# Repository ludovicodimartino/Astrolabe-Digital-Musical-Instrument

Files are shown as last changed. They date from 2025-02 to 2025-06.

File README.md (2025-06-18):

# Astrolabio project

Research training project for the Master's Degree Program in Computer Engineering. The topic of the activity is the design and development of the digital musical instrument based on the astrolabe from the [_Giovanni Poleni_ museum](https://www.musei.unipd.it/it/fisica#) in Padua for the show _Caravanserraglio_.

## Project Structure

```
Astrolabio project
│
└───Arduino Sketches                   # The developed sketches for the Arduino board
│
└───Controller Design                  # The designed parts for building the physical controller
│
└───Digital Twin Desktop Application   # Electron app for viewing the 3D astrolabe model
│
└───Fritzing Breadboard Diagrams       # The design of the breadboards for the first and second design iteration
│
└───PureData Patches                   # The developed Pure Data patches
│   │
│   └───abstractions                   # Reusable Pure Data Objects for reading the sensor data from the network
│   │
│   └───tests                          # Patches for testing the communication with the Arduino
│
└─── README.md
```

## Hardware Components

For the final prototype, the following components were used:

-   [ESP32-C3 Super Mini Dev Board](https://www.espboards.dev/esp32/esp32-c3-super-mini/)
-   [Adafruit Precision NXP 9-DOF Breakout Board - FXOS8700 + FXAS21002](https://www.adafruit.com/product/3463)
-   [Dual rotary encoder](https://docs.rs-online.com/f0a8/A700000009887456.pdf)
-   [LiPo Rider Plus](https://wiki.seeedstudio.com/Lipo-Rider-Plus/)
-   LiPo Battery 3.7V 1800mAh

For the communication between the microcontroller and the IMU (Adafruit Precision NXP 9-DOF), the I<sup>2</sup>C serial communication system was used. Here’s how everything was wired:
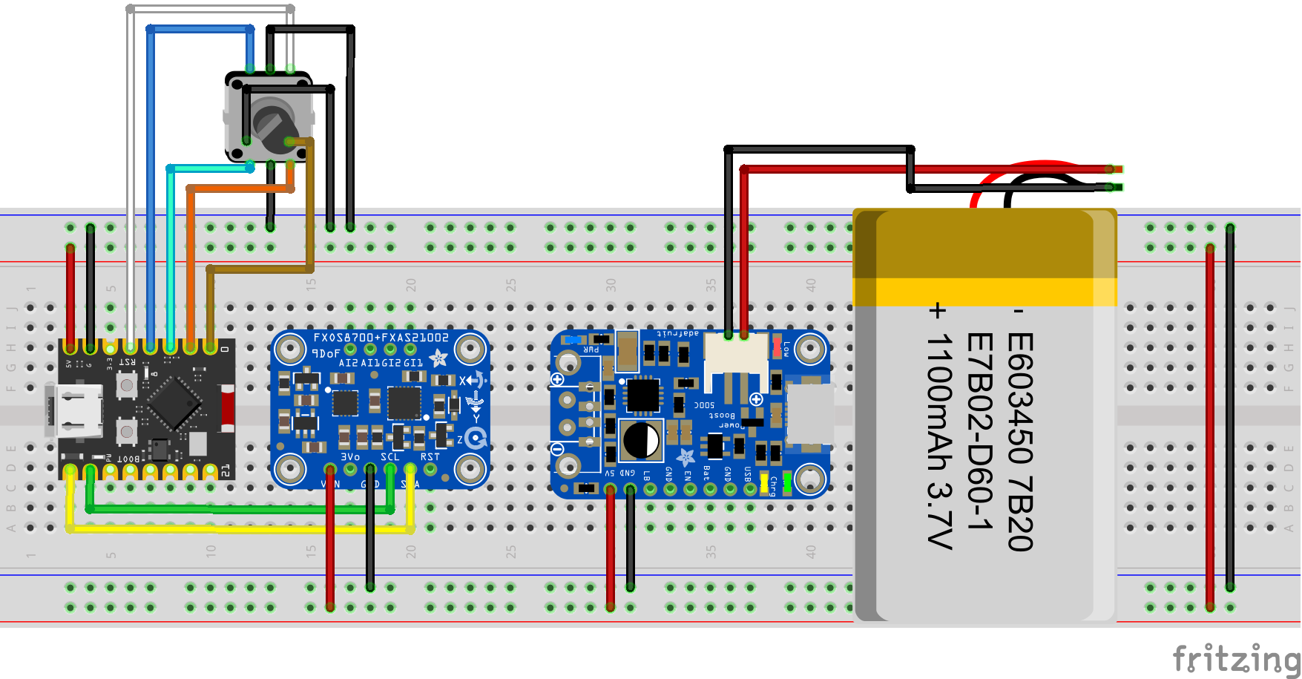
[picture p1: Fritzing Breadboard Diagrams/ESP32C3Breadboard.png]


## How to run the Arduino DMI code on the ESP32-C3 Dev board

1.  In the Arduino IDE, go to File->Preferences and under _Additional boards manager URLs_ paste this URL:

        https://raw.githubusercontent.com/espressif/arduino-esp32/gh-pages/package_esp32_index.json

    If you have other URLs you can separate them using a comma.

2.  In the Arduino IDE, go to the library manager and install all the necessary libraries:
    - [WiFi101](https://docs.arduino.cc/libraries/wifi101/)
    - [Adafruit AHRS](https://github.com/adafruit/Adafruit_AHRS)
    - [Adafruit FXAS21002C](https://github.com/adafruit/Adafruit_FXAS21002C)
    - [Adafruit FXOS8700](https://github.com/adafruit/Adafruit_FXOS8700)
    - [OSC](https://github.com/CNMAT/OSC)
3.  Write the necessary information in the [secrets.h](./Arduino%20Sketches/ESP32C3_send_IMU_and_encoder_Data_OSC/secrets.h) file to allow the board to access WiFi. If the file doesn't exist create it in the sketch directory.
4. In the Arduino IDE, enable the USB CDC on boot (*Tools -> USB CDC On Boot -> Enabled*).
5. Connect the board to the computer, compile and upload the code.

## How to run the Electron App 

### Production version (Windows)
From the [releases](https://github.com/ludovicodimartino/astrolabio-arduino/releases) download the latest Installer version.
Run the installer on your laptop and the program should start automatically.

### Dev version
You must have node.js installed in your system. You can download it from [here](https://nodejs.org/en).

Clone the repository.

Navigate to the [Digital Twin Desktop Application](./Digital%20Twin%20Desktop%20Application/) folder and run the following command:

    npm install

To start the application in development mode run:

    npm start

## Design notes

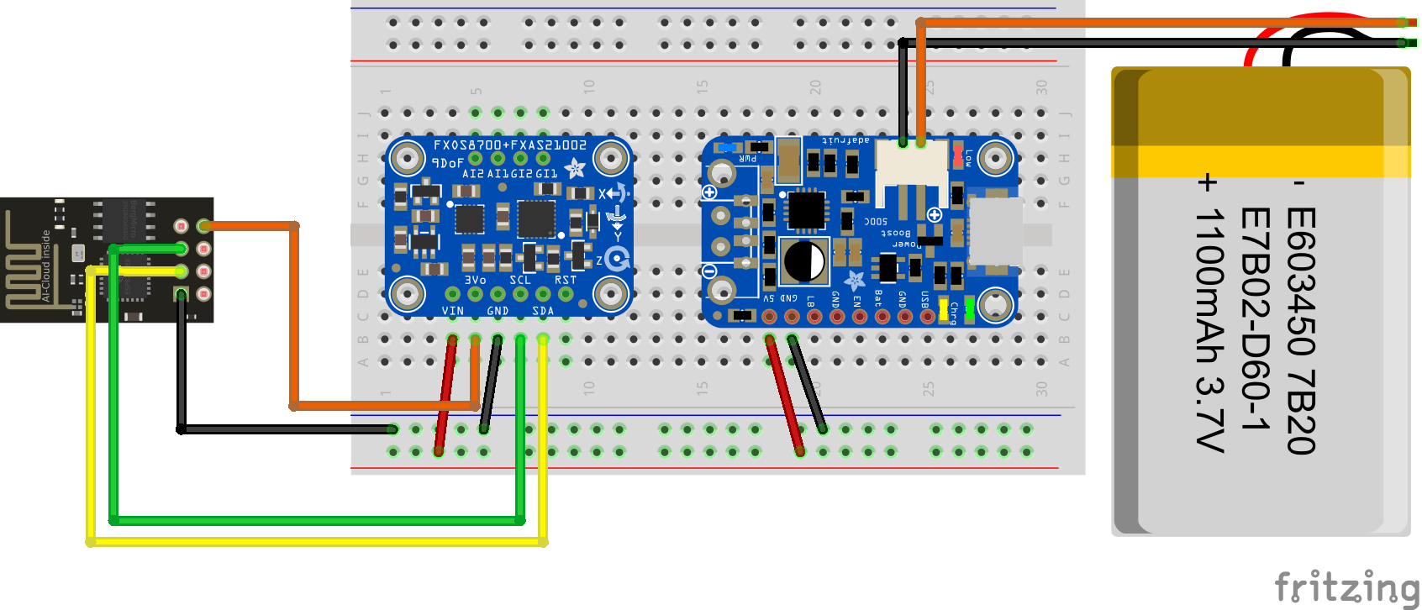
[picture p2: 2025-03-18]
Fritzing Breadboard Diagrams/ESP01SBreadboard.png

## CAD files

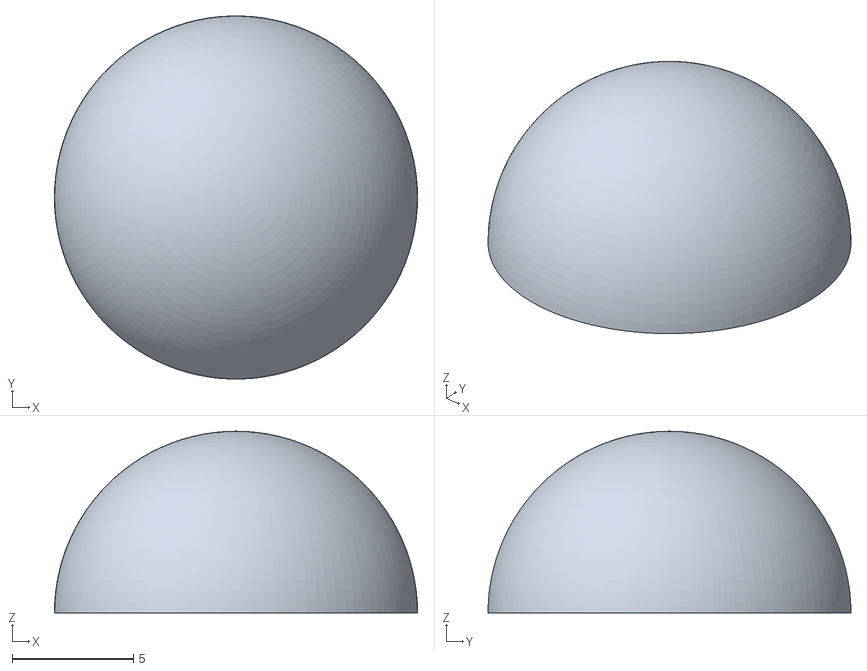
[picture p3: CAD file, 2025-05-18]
Controller Design/Second Iteration/3D Models Rotary Encoder Interface/alidada_interface_with_rotary_encoder.stl
15.0 x 15.0 x 7.50

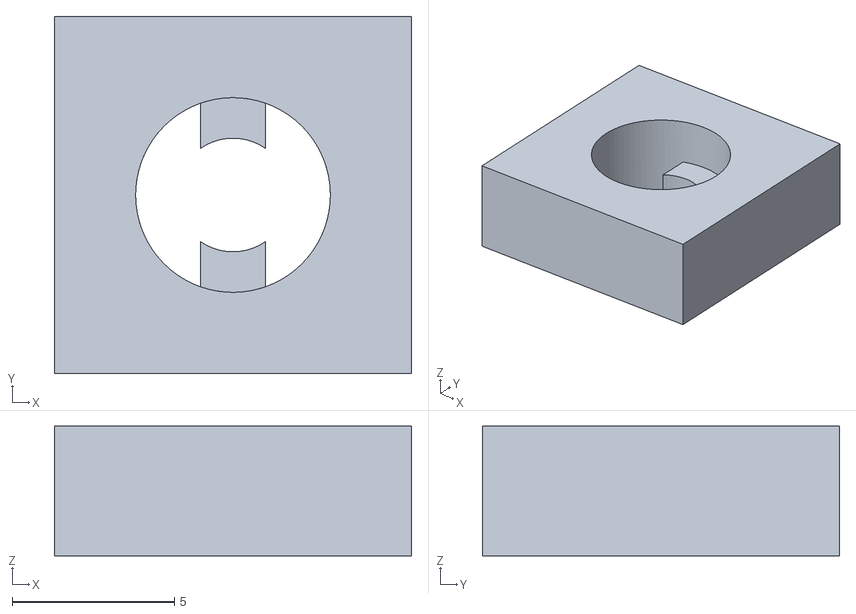
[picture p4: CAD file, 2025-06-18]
Controller Design/Third Iteration/3D Models Rotary Encoder Interface/rete_interface_with_rotary_encoder.stl
11.0 x 11.0 x 4.00

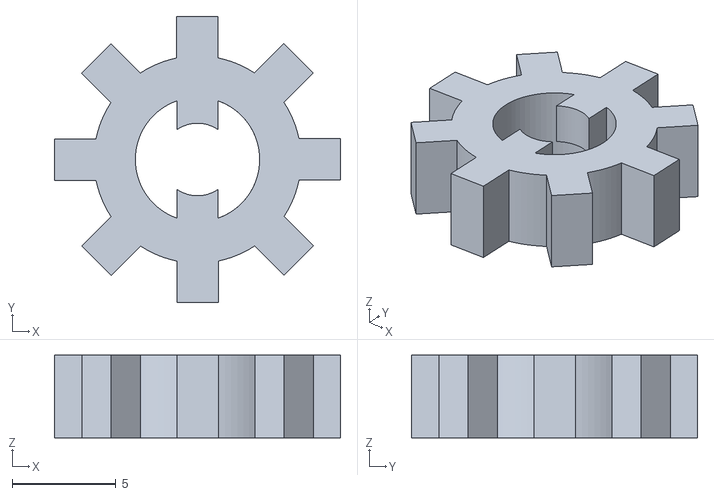
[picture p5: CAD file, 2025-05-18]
Controller Design/Second Iteration/3D Models Rotary Encoder Interface/rete_interface_with_rotary_encoder.stl
13.8 x 13.8 x 4.00

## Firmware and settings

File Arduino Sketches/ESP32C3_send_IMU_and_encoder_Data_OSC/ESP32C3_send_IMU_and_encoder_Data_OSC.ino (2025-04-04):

/**
 * CODE FOR ESP32C3 superMini
 * N.B. REMEMBER TO CREATE THE secrets.h FILE THE WIFI CREDENTIALS AS FOLLOWS
 * #define SECRET_SSID "NetworkName"
 * #define SECRET_PASS "Password"
 *
 * @author Ludovico Di Martino
 */

// Communication libraries
#include <WiFi.h>
#include <WiFiUdp.h>
#include <OSCMessage.h>
#include <OSCBundle.h>

// IMU Sensor libraries
#include <Adafruit_FXAS21002C.h>
#include <Adafruit_FXOS8700.h>
#include <Adafruit_Sensor.h>
#include <Adafruit_Sensor_Calibration.h>

// Library with the secrets (Wifi name and password)
#include "secrets.h"

// The DEBUG variable for debugging purposes (printing in the serial monitor)
// #define DEBUG

#ifdef DEBUG
#define DEBUGPRINTLN Serial.println
#define DEBUGPRINT Serial.print
#else
#define DEBUGPRINTLN  // debug
#define DEBUGPRINT    // debug
#endif

#define DT_A_PIN 4  // Alidada encoder pin 1
#define DT_B_PIN 0   // Rete encoder pin 1
#define CLK_A_PIN 3  // Alidada encoder pin 2
#define CLK_B_PIN 1  // Rete encoder pin 2
#define SW_PIN 2     // Encoder switch pin

#define SDA_PIN 5  // I2C SDA pin (used for the IMU sensor)
#define SCL_PIN 6  // I2C SCL pin (used for the IMU sensor)

#define WIFI_ST_LED 8  // The led that signals the wifi status

#define DEBOUNCE_TIME_SW 2000  // The interval used for switch debouncing

char ssid[] = SECRET_SSID;  // network SSID (name)
char pass[] = SECRET_PASS;  // network pass (use for WPA, or use as key for WEP)

WiFiUDP Udp;                                      // A UDP instance to send and receive packets over UDP
const IPAddress multicastIPAddr(239, 255, 0, 1);  // remote IP address
const unsigned int remotePort = 9999;             // remote port to send OSC
const unsigned int localPort = 8888;              // local port to listen for OSC packets

Adafruit_FXOS8700 accelmag = Adafruit_FXOS8700(0x8700A, 0x8700B);  // assign a unique ID to the accelerometer and magnetometer for the I2C
Adafruit_FXAS21002C gyro = Adafruit_FXAS21002C(0x0021002C);        // assign a unique ID to the gyroscope for the I2C

// Depending on where the calibration data is stored, the cal variable is different
#if defined(ADAFRUIT_SENSOR_CALIBRATION_USE_EEPROM)
Adafruit_Sensor_Calibration_EEPROM cal;
#else
Adafruit_Sensor_Calibration_SDFat cal;
#endif

volatile int32_t counterEncA = 0;         // Counter for the alidade rotary encoder
volatile int32_t counterEncB = 0;         // Counter for the rete rotary encoder
volatile bool newDataToReadEncA = false;  // New data to read for the encoder A
volatile bool newDataToReadEncB = false;  // New data to read for the encoder B
unsigned long lastSwitchPressedTime = 0;  // The last time when a switch press event was detected

#ifdef DEBUG
void displaySensorDetails(void) {
  Serial.print("Calibrations found on ");
  if (cal.hasEEPROM()) Serial.println("EEPROM: ");
  if (cal.hasFLASH()) Serial.println("FLASH: ");
  Serial.print("\tMagnetic Hard Offset: ");
  for (int i = 0; i < 3; i++) {
    Serial.print(cal.mag_hardiron[i]);
    if (i != 2) Serial.print(", ");
  }
  Serial.println();

  Serial.print("\tMagnetic Soft Offset: ");
  for (int i = 0; i < 9; i++) {
    Serial.print(cal.mag_softiron[i]);
    if (i != 8) Serial.print(", ");
  }
  Serial.println();

  Serial.print("\tMagnetic Field Magnitude: ");
  Serial.println(cal.mag_field);

  Serial.print("\tGyro Zero Rate Offset: ");
  for (int i = 0; i < 3; i++) {
    Serial.print(cal.gyro_zerorate[i]);
    if (i != 2) Serial.print(", ");
  }
  Serial.println();

  Serial.print("\tAccel Zero G Offset: ");
  for (int i = 0; i < 3; i++) {
    Serial.print(cal.accel_zerog[i]);
    if (i != 2) Serial.print(", ");
  }
  Serial.println();

  sensor_t accel, mag, gyroSensor;
  accelmag.getSensor(&accel, &mag);
  Serial.println("------------------------------------");
  Serial.println("ACCELEROMETER");
  Serial.println("------------------------------------");
  Serial.print("Sensor:       ");
  Serial.println(accel.name);
  Serial.print("Driver Ver:   ");
  Serial.println(accel.version);
  Serial.print("Unique ID:    0x");
  Serial.println(accel.sensor_id, HEX);
  Serial.print("Min Delay:    ");
  Serial.print(accel.min_delay);
  Serial.println(" s");
  Serial.print("Max Value:    ");
  Serial.print(accel.max_value, 4);
  Serial.println(" m/s^2");
  Serial.print("Min Value:    ");
  Serial.print(accel.min_value, 4);
  Serial.println(" m/s^2");
  Serial.print("Resolution:   ");
  Serial.print(accel.resolution, 8);
  Serial.println(" m/s^2");
  Serial.println("------------------------------------");
  Serial.println("");
  Serial.println("------------------------------------");
  Serial.println("MAGNETOMETER");
  Serial.println("------------------------------------");
  Serial.print("Sensor:       ");
  Serial.println(mag.name);
  Serial.print("Driver Ver:   ");
  Serial.println(mag.version);
  Serial.print("Unique ID:    0x");
  Serial.println(mag.sensor_id, HEX);
  Serial.print("Min Delay:    ");
  Serial.print(accel.min_delay);
  Serial.println(" s");
  Serial.print("Max Value:    ");
  Serial.print(mag.max_value);
  Serial.println(" uT");
  Serial.print("Min Value:    ");
  Serial.print(mag.min_value);
  Serial.println(" uT");
  Serial.print("Resolution:   ");
  Serial.print(mag.resolution);
  Serial.println(" uT");
  Serial.println("------------------------------------");
  Serial.println("");
  gyro.getSensor(&gyroSensor);
  Serial.println("------------------------------------");
  Serial.println("GYROSCOPE");
  Serial.println("------------------------------------");
  Serial.print("Sensor:       ");
  Serial.println(gyroSensor.name);
  Serial.print("Driver Ver:   ");
  Serial.println(gyroSensor.version);
  Serial.print("Unique ID:    0x");
  Serial.println(gyroSensor.sensor_id, HEX);
  Serial.print("Max Value:    ");
  Serial.print(gyroSensor.max_value);
  Serial.println(" rad/s");
  Serial.print("Min Value:    ");
  Serial.print(gyroSensor.min_value);
  Serial.println(" rad/s");
  Serial.print("Resolution:   ");
  Serial.print(gyroSensor.resolution);
  Serial.println(" rad/s");
  Serial.println("------------------------------------");
  Serial.println("");
  delay(500);
}
#endif

void WiFiStationConnected(WiFiEvent_t event, WiFiEventInfo_t info) {
  // Signaling the connection with the led
  digitalWrite(WIFI_ST_LED, LOW);

  DEBUGPRINTLN("Connection succeeded!");
  DEBUGPRINTLN("----------------------------------------");
#ifdef DEBUG
  Serial.println("Board WiFi Information:");
  // print the board's IP address
  IPAddress ip = WiFi.localIP();
  Serial.print("IP Address: ");
  Serial.println(ip);

  Serial.println();
  Serial.println("Network Information:");
  Serial.print("SSID: ");
  Serial.println(WiFi.SSID());

  // print the received signal strength
  long rssi = WiFi.RSSI();
  Serial.print("signal strength (RSSI): ");
  Serial.println(rssi);
#endif
  DEBUGPRINTLN("----------------------------------------");

  // Initializing the UDP
  DEBUGPRINTLN("Starting UDP...");
  Udp.begin(localPort);
  DEBUGPRINT("Local port: ");
  DEBUGPRINTLN(localPort);
  DEBUGPRINTLN("----------------------------------------");
  DEBUGPRINTLN("");
  DEBUGPRINT("Sending data to: ");
  DEBUGPRINT(multicastIPAddr);
  DEBUGPRINT(":");
  DEBUGPRINTLN(remotePort);
}

void WiFiStationDisconnected(WiFiEvent_t event, WiFiEventInfo_t info) {
  // Signaling the disconnection with the led
  digitalWrite(WIFI_ST_LED, HIGH);

  DEBUGPRINT("WiFi lost connection. Reason: ");
  DEBUGPRINTLN(info.wifi_sta_disconnected.reason);
  DEBUGPRINTLN("Trying to Reconnect");
}

IRAM_ATTR void rotary_dt_A_down() {
  // encoder in 00 state, pin 1 jumped down last
  if (digitalRead(CLK_A_PIN) == 0) {
    counterEncA--;
    newDataToReadEncA = true;
    attachInterrupt(digitalPinToInterrupt(DT_A_PIN), rotary_dt_A_up, RISING);
    detachInterrupt(digitalPinToInterrupt(CLK_A_PIN));
  }
  // encoder in 01 state, waiting for pin 2 to jump down
  else {
    detachInterrupt(digitalPinToInterrupt(DT_A_PIN));
    attachInterrupt(digitalPinToInterrupt(CLK_A_PIN), rotary_clk_A_down, FALLING);
  }
}

IRAM_ATTR void rotary_clk_A_down() {
  // encoder in 00 state, pin 2 jumped down last
  if (digitalRead(DT_A_PIN) == 0) {
    counterEncA++;
    newDataToReadEncA = true;
    attachInterrupt(digitalPinToInterrupt(DT_A_PIN), rotary_dt_A_up, RISING);
    detachInterrupt(digitalPinToInterrupt(CLK_A_PIN));
  }
  // encoder in 10 state, waiting for pin 1 to jump down
  else {
    attachInterrupt(digitalPinToInterrupt(DT_A_PIN), rotary_dt_A_down, FALLING);
    detachInterrupt(digitalPinToInterrupt(CLK_A_PIN));
  }
}

IRAM_ATTR void rotary_dt_A_up() {
  // encoder in 11 state, pin 1 jumped up last
  if (digitalRead(CLK_A_PIN) == 1) {
    counterEncA--;
    newDataToReadEncA = true;
    attachInterrupt(digitalPinToInterrupt(DT_A_PIN), rotary_dt_A_down, FALLING);
    detachInterrupt(digitalPinToInterrupt(CLK_A_PIN));
  }
  // encoder in 10 state, waiting for pin 2 to jump up
  else {
    detachInterrupt(digitalPinToInterrupt(DT_A_PIN));
    attachInterrupt(digitalPinToInterrupt(CLK_A_PIN), rotary_clk_A_up, RISING);
  }
}

IRAM_ATTR void rotary_clk_A_up() {
  // encoder in 11 state, pin 2 jumped up last
  if (digitalRead(DT_A_PIN) == HIGH) {
    counterEncA++;
    newDataToReadEncA = true;
    attachInterrupt(digitalPinToInterrupt(DT_A_PIN), rotary_dt_A_down, FALLING);
    detachInterrupt(digitalPinToInterrupt(CLK_A_PIN));
  }
  // encoder in 01 state, waiting for pin 1 to jump up
  else {
    attachInterrupt(digitalPinToInterrupt(DT_A_PIN), rotary_dt_A_up, RISING);
    detachInterrupt(digitalPinToInterrupt(CLK_A_PIN));
  }
}

IRAM_ATTR void rotary_dt_B_down() {
  // encoder in 00 state, pin 1 jumped down last
  if (digitalRead(CLK_B_PIN) == 0) {
    counterEncB--;
    newDataToReadEncB = true;
    attachInterrupt(digitalPinToInterrupt(DT_B_PIN), rotary_dt_B_up, RISING);
    detachInterrupt(digitalPinToInterrupt(CLK_B_PIN));
  }
  // encoder in 01 state, waiting for pin 2 to jump down
  else {
    detachInterrupt(digitalPinToInterrupt(DT_B_PIN));
    attachInterrupt(digitalPinToInterrupt(CLK_B_PIN), rotary_clk_B_down, FALLING);
  }
}

IRAM_ATTR void rotary_clk_B_down() {
  // encoder in 00 state, pin 2 jumped down last
  if (digitalRead(DT_B_PIN) == 0) {
    counterEncB++;
    newDataToReadEncB = true;
    attachInterrupt(digitalPinToInterrupt(DT_B_PIN), rotary_dt_B_up, RISING);
    detachInterrupt(digitalPinToInterrupt(CLK_B_PIN));
  }
  // encoder in 10 state, waiting for pin 1 to jump down
  else {
    attachInterrupt(digitalPinToInterrupt(DT_B_PIN), rotary_dt_B_down, FALLING);
    detachInterrupt(digitalPinToInterrupt(CLK_B_PIN));
  }
}

IRAM_ATTR void rotary_dt_B_up() {
  // encoder in 11 state, pin 1 jumped up last
  if (digitalRead(CLK_B_PIN) == 1) {
    counterEncB--;
    newDataToReadEncB = true;
    attachInterrupt(digitalPinToInterrupt(DT_B_PIN), rotary_dt_B_down, FALLING);
    detachInterrupt(digitalPinToInterrupt(CLK_B_PIN));
  }
  // encoder in 10 state, waiting for pin 2 to jump up
  else {
    detachInterrupt(digitalPinToInterrupt(DT_B_PIN));
    attachInterrupt(digitalPinToInterrupt(CLK_B_PIN), rotary_clk_B_up, RISING);
  }
}

IRAM_ATTR void rotary_clk_B_up() {
  // encoder in 11 state, pin 2 jumped up last
  if (digitalRead(DT_B_PIN) == HIGH) {
    counterEncB++;
    newDataToReadEncB = true;
    attachInterrupt(digitalPinToInterrupt(DT_B_PIN), rotary_dt_B_down, FALLING);
    detachInterrupt(digitalPinToInterrupt(CLK_B_PIN));
  }
  // encoder in 01 state, waiting for pin 1 to jump up
  else {
    attachInterrupt(digitalPinToInterrupt(DT_B_PIN), rotary_dt_B_up, RISING);
    detachInterrupt(digitalPinToInterrupt(CLK_B_PIN));
  }
}

void setup() {
#ifdef DEBUG
  // Serial monitor setup
  Serial.begin(115200);
  while (!Serial) {
    delay(500);
  }
  DEBUGPRINTLN("Debug Mode");
#endif

  // Initialize the status LED
  pinMode(WIFI_ST_LED, OUTPUT);

  // Turn off the status led (on by default)
  digitalWrite(WIFI_ST_LED, HIGH);

  // I2C communication pins: set SDA pin and SCL pin
  Wire.begin(SDA_PIN, SCL_PIN);

  // load the calibration for the IMU
  bool calBegin = cal.begin();
  bool loadCal = cal.loadCalibration();
  if (!calBegin) {
    DEBUGPRINTLN("Failed to initialize calibration helper");
  } else if (!loadCal) {
    DEBUGPRINTLN("No calibration loaded/found");
  }

  // accelerometer and magnetometer initialization
  if (!accelmag.begin()) {
    // There was a problem detecting the FXOS8700
    DEBUGPRINTLN("No FXOS8700 detected ... Check your wiring!");
    while(1) delay(10);
  }

  // gyroscope initialization
  if (!gyro.begin()) {
    // there was a problem detecting the FXAS21002C
    DEBUGPRINTLN("No FXAS21002C detected ... Check your wiring!");
    while(1) delay(10);
  }

#ifdef DEBUG
  // print sensor data
  displaySensorDetails();
#endif

  // Initialize the pins for the rotary encoders with the internal pullup
  pinMode(DT_A_PIN, INPUT_PULLUP);
  pinMode(DT_B_PIN, INPUT_PULLUP);
  pinMode(CLK_A_PIN, INPUT_PULLUP);
  pinMode(CLK_B_PIN, INPUT_PULLUP);
  pinMode(SW_PIN, INPUT_PULLUP);

  // Read the initial encoder states
  int8_t dt_A = digitalRead(DT_A_PIN);
  int8_t clk_A = digitalRead(CLK_A_PIN);
  int8_t dt_B = digitalRead(DT_B_PIN);
  int8_t clk_B = digitalRead(CLK_B_PIN);

  
  DEBUGPRINT("Encoder A position");
  DEBUGPRINT(" dt_A:");
  DEBUGPRINT(dt_A);
  DEBUGPRINT(" clk_A:");
  DEBUGPRINTLN(clk_A);
  // Initial position of the encoder A 00 or 01
  if (((dt_A == LOW) && (clk_A == LOW) || ((dt_A == LOW) && (clk_A == HIGH)))) {
    attachInterrupt(digitalPinToInterrupt(DT_A_PIN), rotary_dt_A_up, RISING);
  }
  // Initial position of the encoder A 11 or 10
  else {
    attachInterrupt(digitalPinToInterrupt(DT_A_PIN), rotary_dt_A_down, FALLING);
  }

  
  DEBUGPRINT("Encoder B position");
  DEBUGPRINT(" dt_B:");
  DEBUGPRINT(dt_B);
  DEBUGPRINT(" clk_B:");
  DEBUGPRINTLN(clk_B);
  // Initial position of the encoder B 00 or 01
  if (((dt_B == LOW) && (clk_B == LOW)) || ((dt_B == LOW) && (clk_B == HIGH))) {
    attachInterrupt(digitalPinToInterrupt(DT_B_PIN), rotary_dt_B_up, RISING);
  }
  // Initial position of the encoder B 11 or 10
  else {
    attachInterrupt(digitalPinToInterrupt(DT_B_PIN), rotary_dt_B_down, FALLING);
  }

  // network connection
  DEBUGPRINT("Attempting to connect to network: ");
  DEBUGPRINTLN(ssid);

  // Set the Wifi mode
  WiFi.mode(WIFI_STA);

  // Delete the old configurations
  WiFi.disconnect(true);

  delay(1000);

  WiFi.onEvent(WiFiStationConnected, WiFiEvent_t::ARDUINO_EVENT_WIFI_STA_GOT_IP);
  WiFi.onEvent(WiFiStationDisconnected, WiFiEvent_t::ARDUINO_EVENT_WIFI_STA_DISCONNECTED);

  WiFi.begin(ssid, pass);

  // Wait for the connection to be ready
  while (WiFi.status() != WL_CONNECTED) {
    delay(100);
  }

  // Send initial reset message to the client
  OSCMessage msg("/reset");
  Udp.beginPacket(multicastIPAddr, remotePort);
  msg.send(Udp);
  Udp.endPacket();
  msg.empty();
}

void loop() {
  // Reading the data from the rotary encoders
  if (newDataToReadEncA) {
    OSCMessage msg("/encA");
    msg.add(counterEncA);
    Udp.beginPacket(multicastIPAddr, remotePort);
    msg.send(Udp);
    Udp.endPacket();
    msg.empty();
    DEBUGPRINTLN(counterEncA);
    newDataToReadEncA = false;
  }
  if (newDataToReadEncB) {
    OSCMessage msg("/encB");
    msg.add(counterEncB);
    Udp.beginPacket(multicastIPAddr, remotePort);
    msg.send(Udp);
    Udp.endPacket();
    msg.empty();
    DEBUGPRINTLN(counterEncB);
    newDataToReadEncB = false;
  }

  // Check if the switch was pressed
  unsigned long currentTime = millis();
  // Debounce logic (Ignore interrupts within DEBOUNCE_TIME_SW)
  if (currentTime - lastSwitchPressedTime > DEBOUNCE_TIME_SW && digitalRead(SW_PIN) == LOW) {
    // reset the counters
    counterEncA = 0;
    counterEncB = 0;
    DEBUGPRINTLN("ENCODER SWITCH PRESSED");

    // send reset message
    OSCMessage msg("/reset");
    Udp.beginPacket(multicastIPAddr, remotePort);
    msg.send(Udp);
    Udp.endPacket();
    msg.empty();
    lastSwitchPressedTime = currentTime;
  }

  sensors_event_t aevent, mevent, gevent;

  // get new sensors event
  accelmag.getEvent(&aevent, &mevent);
  gyro.getEvent(&gevent);

  // calibration step
  // cal.calibrate(mevent);
  // cal.calibrate(aevent);
  // cal.calibrate(gevent);

  // Prepare an OSC bundle message
  OSCBundle bundle;

  // accelerometer data
  bundle.add("/acc/x").add(aevent.acceleration.x);
  bundle.add("/acc/y").add(aevent.acceleration.y);
  bundle.add("/acc/z").add(aevent.acceleration.z);

  // magnetometer data
  bundle.add("/mag/x").add(mevent.magnetic.x);
  bundle.add("/mag/y").add(mevent.magnetic.y);
  bundle.add("/mag/z").add(mevent.magnetic.z);

  // gyroscope data
  bundle.add("/gyro/x").add(gevent.gyro.x);
  bundle.add("/gyro/y").add(gevent.gyro.y);
  bundle.add("/gyro/z").add(gevent.gyro.z);

  // send the message
  Udp.beginPacket(multicastIPAddr, remotePort);
  bundle.send(Udp);
  Udp.endPacket();
  bundle.empty();
  delay(50);
}

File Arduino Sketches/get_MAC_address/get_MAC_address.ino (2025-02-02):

/*
  This code is used to get the MAC address of the ESP-01S master.
  The MAC address will be used by the slaves to communicate with the master. 
*/
#include <ESP8266WiFi.h>

void setup(){
  Serial.begin(115200);
  Serial.print("ESP Board MAC Address: ");
  Serial.println(WiFi.macAddress());
}
 
void loop(){

}

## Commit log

2024-10-12 add arduino sketches and PureData patch
2024-11-04 add Electron app and sensor fusion
2024-11-18 add debug and reconnection in case of connection lost
2024-12-03 add WiFi status led
2025-01-23 add Arduino Nano 33 IoT code
2025-03-09 dual rotary encoder preliminary test
2025-03-10 add reset counters when encoder pressed
    [rotary_encoder_test.ino]
2025-03-10 render astrolabe and listen for encoder OSC messages
2025-03-12 add code for the ESP32C3
2025-03-18 add IMU calibration
2025-03-18 improve sensor fusion
2025-03-18 add gyro calibration
2025-03-19 remove not working calibration
    [ESP32C3_send_IMU_and_encoder_Data_OSC.ino]
2025-03-19 add encoders to the sensor receive pd abstraction
2025-03-24 add OSC message benchmark sketch for sensor data transmission
2025-03-24 refactor sensor-receive abstraction for improved routing and help documentation
2025-03-26 improve rotary encoder debouncing
2025-04-04 change pin to match perfboard prototype
2025-04-12 Madgwick filter implementation
2025-05-18 add Controller Design folder
    [alidada_interface_with_rotary_encoder.stl, rete_interface_with_rotary_encoder.stl]
2025-05-18 Temporary rename folders to force case change
2025-06-18 updated controller design
    [alidada_interface_with_rotary_encoder.stl, rete_interface_with_rotary_encoder.stl]
2025-07-03 remove ground plane improved lighting and add stars moving with the rete
